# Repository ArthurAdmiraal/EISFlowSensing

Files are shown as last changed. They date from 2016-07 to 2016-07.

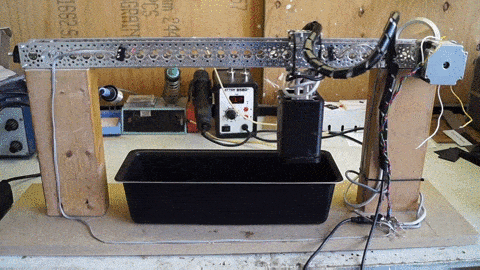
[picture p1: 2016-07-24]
Documentation/Render/CompleteSetup.gif

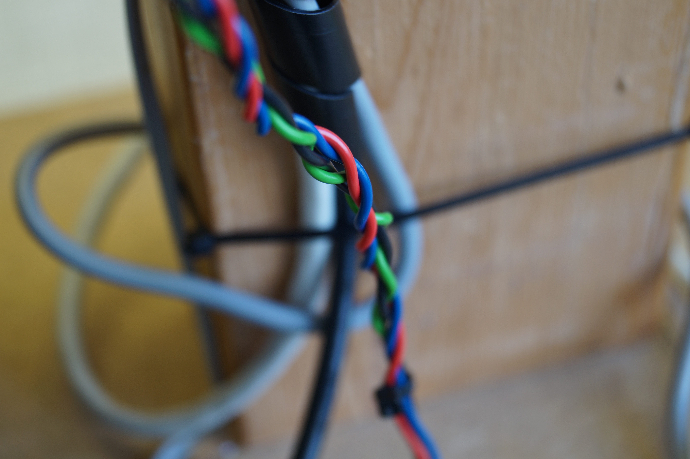
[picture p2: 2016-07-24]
Documentation/Render/StepperMotorWiring.jpg

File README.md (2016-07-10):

# Solid state flow sensing using Electrical Impedance Spectroscopy
This repository contains all files for the solid state flow sensing using EIS project, which is documented on hackaday.io, click [here](https://hackaday.io/project/12543-solid-state-flow-sensing-using-eis) to go there.

## License
You can use everything here under a[Creative Commons Attribution-ShareAlike 4.0 International](https://creativecommons.org/licenses/by-sa/4.0/) license.

## Repository structure
Inside the documentation folder, you'll find the source files for images used in the documentation of the project on hackaday.io, along with the rendered versions. The source images are either vector files, or images to large to be uploaded to hackaday.io. You can also find software examples for tutorials placed on hackaday.io there.

The design folder contains CAD files and CAM files needed for replicating the project. The electrical folder contains the KiCad projects for both the electrode and signal generator PCB, along with the gerbers to get them fabricated at [OSH Park](https://oshpark.com/). The mechanical folder contains some OpenScad files for 3D-printed parts, along with STLs for the files that take a long time to render.

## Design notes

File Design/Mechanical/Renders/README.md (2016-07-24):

#Renders
In this folder, you find all the stl files you need for 3D printing the RISA case. You could also download the OpenSCAD source file in the design folder if you want to edit the model or render our the files yourself, but since the rendering takes a long time (about half a hour for me) I have provided the rendered out files here too.

#The files
## Files to 3D-print
If you just want to build this project for yourself, you can simply download these files and hit print.

### RISA_Case_O_ring_USB_Space_top_fixed.stl
This is the top of the case, or the electrode holder part. The mesh was repaired from the source file using [Microsofts 3D printing cloud services](https://tools3d.azurewebsites.net/) to make it suitable for 3D printing.

### RISA_Case_O_ring_USB_Space_body.stl
This is the main body of the case. The mesh isn't watertight, as I wasn't able to repair it automatically. The slicer I use (Slic3r) didn't have any problems with it though.

## Additional files
###RISA_Case_O_ring_USB_Space_full.stl
This is the full case, in case you need it. It isn't really 3D-printable on entry-level 3D printers, but perhaps you want to do something fancier.

###RISA_Case_O_ring_USB_Space_top.stl
This is the top of the case, or the electrode holder part, as it rendered out of OpenSCAD. Unfortunately, the mesh isn't quite watertight, which can lead slicers to have problems with it. I have included it for completeness.

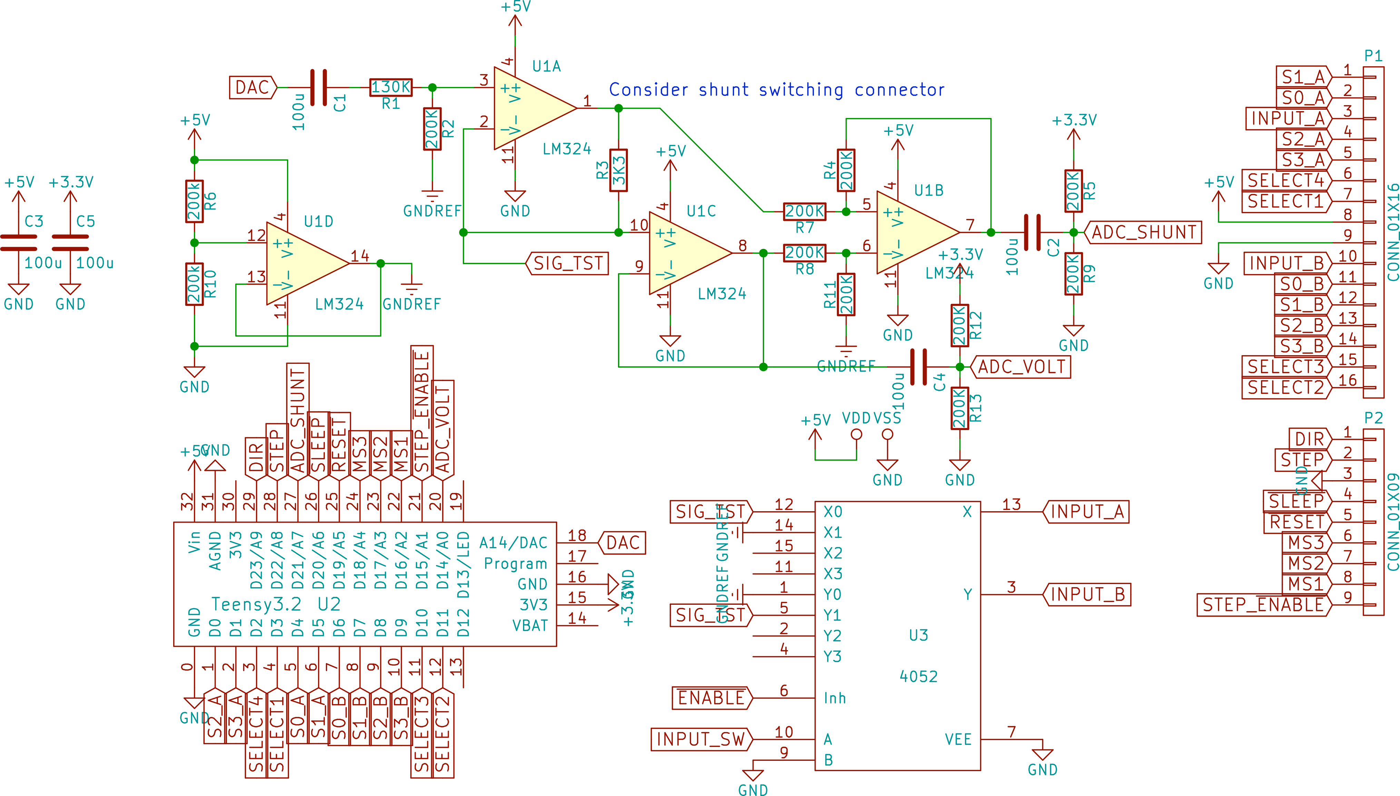
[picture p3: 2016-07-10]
Documentation/Render/SigGenSchematic.png

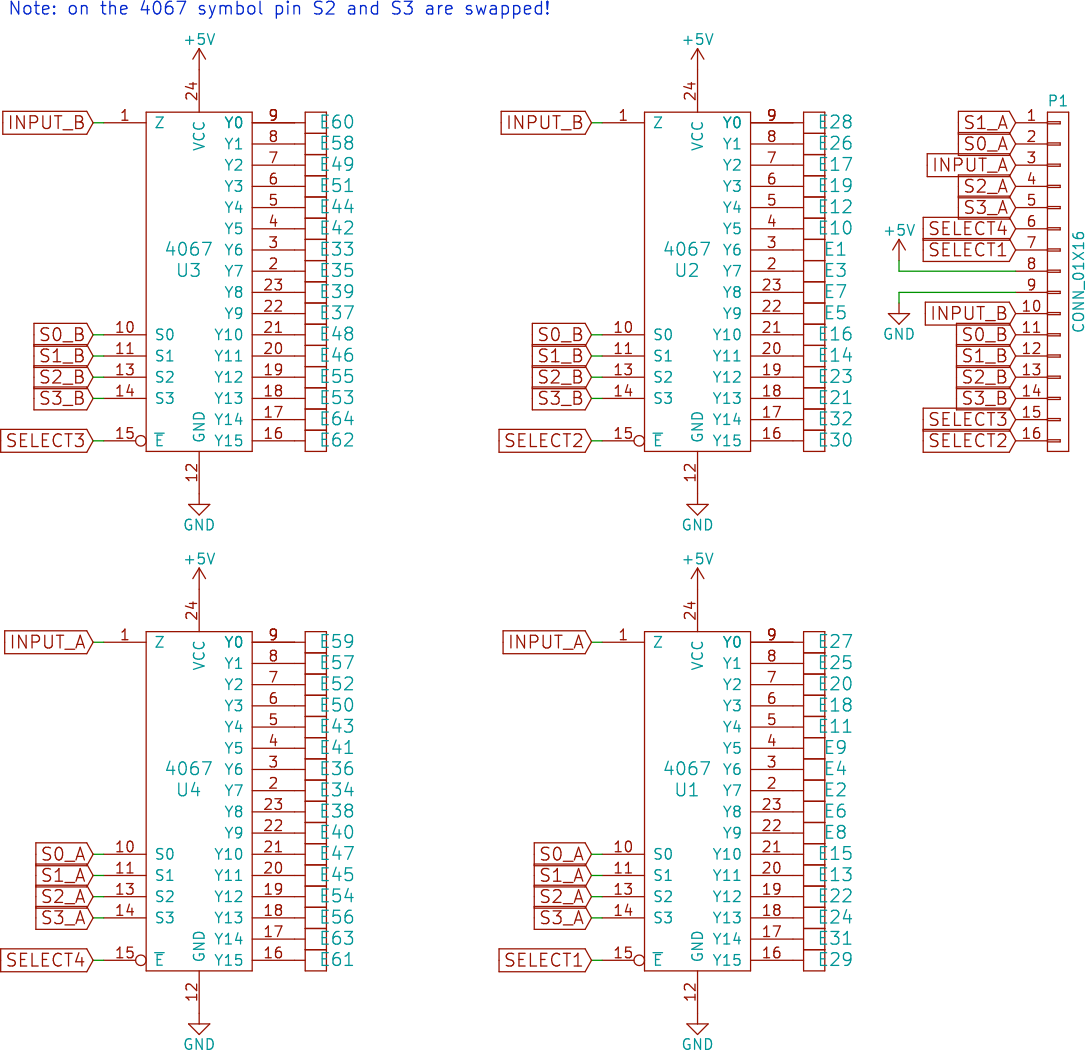
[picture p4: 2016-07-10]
Documentation/Render/ElectrodeSchematic.png

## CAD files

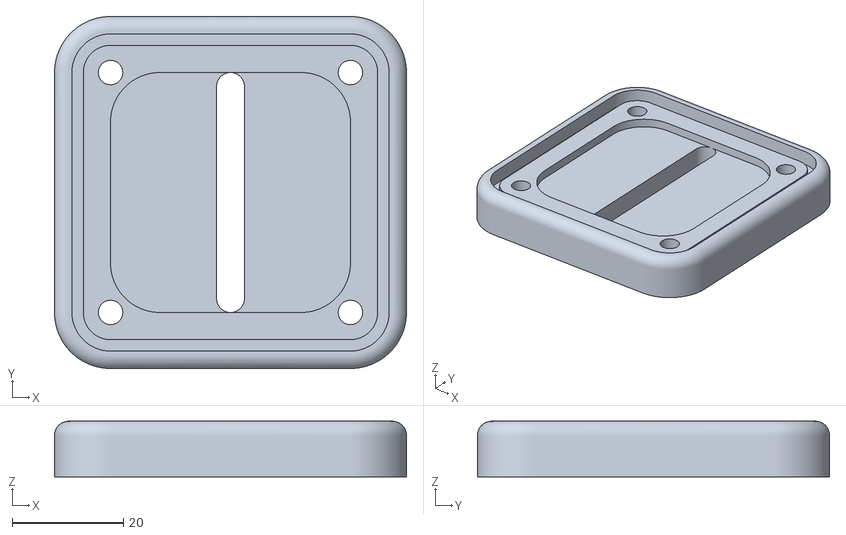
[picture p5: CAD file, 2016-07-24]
Design/Mechanical/Renders/RISA_Case_O_ring_USB_Space_top_fixed.stl
63.4 x 63.4 x 10.00

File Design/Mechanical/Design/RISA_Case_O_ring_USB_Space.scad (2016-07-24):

// quality settings
$fs = 0.05;
$fa = 2;

// CAM parameters
split = 10;

// parameters
margin          = 1.2;              // 1.2mm
topBevel        = 0.1*25.4;         // 0.1"
sideBevel       = 0.35*25.4+margin; // 0.35"
holeDist        = 0.85*25.4;        // 0.85"
height          = 100;              // 100mm
interconnect    = 12.8;             // 12.4mm, change this value
electrodeSize   = 2.2*25.4+margin;  // 2.2"
sigGenSize      = 2.0*25.4+margin*2;// 2.0"
pcbThickness    = 1.6;              // 1.6mm
holeSize        = 3.2 + margin;     // M3 clearance hole
componentSize   = 2.0;              // 2mm component clearance
componentRadius = 0.35*25.4;        // 0.35"
headerWidth     = 1.7*25.4;         // 1.7"
headerHeight    = 0.15*25.4+margin; // 0.15"
hubSize         = 1.061*25.4;       // 1.061"
hubOffset       = 0.22*25.4;        // 0.22"
hubHole         = 1.85+margin/2;    // #6-32 clearance radius, 1.85mm
hubWidth        = 2.05*25.4+margin; // 2.05"
hubHeight       = 1.25*25.4;        // 1.25"
hubRadius       = 0.75*25.4;        // 0.75"
angle           = 45;               // 45 degrees

extension      =  7+2*margin;
extensionBegin = 9;
extensionAngle = 45; // there is probably an error in calculations involving this angle, so best keep it on this
angleMargin    = 0.001;

extensionOffset = 2*sideBevel*(1-cos(extensionAngle));
slopedExtension = (extension - extensionOffset)/cos(extensionAngle);
extensionHeight = 2*sideBevel*sin(extensionAngle) + sin(extensionAngle)*slopedExtension;

// helper modules
// basic shapes
module torus(rminor, rmajor) {
    rotate_extrude() {
        translate([rmajor,0,0])
            circle(r=rminor);
    }
}

// building the object
// change intersection to difference for the bottom part
intersection() { difference() {
translate([0,0,-topBevel]) union() {
////////////////////////////////////////////////////////////
// top /////////////////////////////////////////////////////
////////////////////////////////////////////////////////////
union() {
// top corner bevels
for(o=[[1,1,0],[1,-1,0],[-1,1,0],[-1,-1,0]]) {
    translate(holeDist*o) {
        torus(topBevel, sideBevel-topBevel);
        cylinder(r=sideBevel-topBevel, h=2*topBevel, center=true);
    }
}

// top side bevels
for(o=[[1,0,0],[-1,0,0],[0,1,0],[0,-1,0]]) {
    translate((holeDist+sideBevel-topBevel)*o)
    rotate(90*o)
    cylinder(r=topBevel, h=2*holeDist, center=true);
}

// top filler
cube(2*[holeDist+sideBevel-topBevel,holeDist,topBevel], center=true);
cube(2*[holeDist,holeDist+sideBevel-topBevel,topBevel], center=true);
}

////////////////////////////////////////////////////////////
// main body ///////////////////////////////////////////////
////////////////////////////////////////////////////////////
// more comment comming for this part
translate([0,0,topBevel-height]) rotate([0,180,0]) union() {
// side bevels
translate([0,0,topBevel-height]) {
    for(o=[[1,-1,0],[-1,-1,0]]) {
        translate(holeDist*o)
        cylinder(r=sideBevel, h=height-topBevel);
    }
    
    for(o=[[1,1,0],[-1,1,0]]) {
        translate(holeDist*o)
        union() {
            cylinder(r=sideBevel, h=extensionBegin+angleMargin);
            
            translate([0,sideBevel,extensionBegin]) difference() {
                rotate([0,90,0])
                torus(sideBevel, sideBevel+angleMargin);
                translate([-sideBevel*1.05, 0, -sideBevel*2.1])
                cube([sideBevel*2.1, sideBevel*2.1, sideBevel*4.2]);
                translate([-sideBevel*1.05,-sideBevel*2.1,-sideBevel*2.1])
                cube([sideBevel*2.1, sideBevel*4.2, sideBevel*2.1]);
                translate([-sideBevel*1.05,0,0])
                rotate([extensionAngle-angleMargin,0,0])
                cube([sideBevel*2.1, sideBevel*2.1, sideBevel*2.1]);
            }
            
          translate([0,-sideBevel+extension,extensionBegin+extensionHeight]) {
                rotate([180,0,0]) difference(){
                rotate([0,90,0])
                torus(sideBevel, sideBevel+angleMargin);
                translate([-sideBevel*1.05, 0, -sideBevel*2.1])
                cube([sideBevel*2.1, sideBevel*2.1, sideBevel*4.2]);
                translate([-sideBevel*1.05,-sideBevel*2.1,-sideBevel*2.1])
                cube([sideBevel*2.1, sideBevel*4.2, sideBevel*2.1]);
                translate([-sideBevel*1.05,0,0])
                rotate([extensionAngle-angleMargin,0,0])
                cube([sideBevel*2.1, sideBevel*2.1, sideBevel*2.1]);
                }
            }
            translate([0,extension,extensionBegin+extensionHeight])
            cylinder(r=sideBevel, h=height-topBevel-extensionBegin-extensionHeight);
            
            translate([0,sideBevel,extensionBegin])
            rotate([-extensionAngle,0,0]) union() {
                translate([0,-sideBevel,0])
                cylinder(r=sideBevel, h=slopedExtension+angleMargin);
                translate([-sideBevel,-2*sideBevel,0])
                cube([2*sideBevel,sideBevel,slopedExtension+angleMargin]);
            }
        }
    }
}

translate([0,holeDist+extension-sideBevel,-height+topBevel+extensionBegin+extensionHeight])
rotate([0,90,0]) {
cylinder(r=sideBevel, h=2*(holeDist+sideBevel), center=true);
cylinder(r=2*sideBevel, h=2*(holeDist), center=true);
}

translate([-holeDist-sideBevel,holeDist+sideBevel,topBevel+extensionBegin-height]) {
    rotate([90-extensionAngle,0,0])
    translate([sideBevel,0,0])
    cube([2*holeDist, slopedExtension, sideBevel]);
difference() {
    translate([0,-sideBevel,0])
    cube([2*(holeDist+sideBevel),sideBevel,sideBevel]);
    translate([-0.05*(holeDist+sideBevel),0,0]) {
    rotate([0,90,0]) cylinder(r=sideBevel, h=2.1*(holeDist+sideBevel));
    rotate([extensionAngle,0,0])
    cube([2.1*(holeDist+sideBevel),2*sideBevel,2*sideBevel]);
    }
}
}

translate([0,0.5*extension,-0.5*(height-topBevel-extensionBegin-extensionHeight)]) {
cube([2*(holeDist+sideBevel),2*holeDist+extension,height-topBevel-extensionBegin-extensionHeight],center=true);
cube([2*holeDist,2*(holeDist+sideBevel)+extension,height-topBevel-extensionBegin-extensionHeight],center=true);
}

// main filler
translate(0.5*[0,0,topBevel-height]) {
cube([2*(holeDist+sideBevel),2*holeDist,height-topBevel],center=true);
cube([2*holeDist,2*(holeDist+sideBevel),height-topBevel],center=true);
}
}
}
////////////////////////////////////////////////////////////
// cutouts /////////////////////////////////////////////////
////////////////////////////////////////////////////////////
// main cutout
translate([0,0,-height-1]) {
    for(o=[[1,1,0],[-1,1,0],[1,-1,0],[-1,-1,0]]) {
        translate(holeDist*o)
        cylinder(r=0.5*sigGenSize-holeDist, h=height-pcbThickness-interconnect+1);
    }
    
    translate(0.5*[0,0,height-pcbThickness-interconnect+1]) {
        cube([sigGenSize,2*holeDist,height-pcbThickness-interconnect+1], center=true);
        cube([2*holeDist,sigGenSize,height-pcbThickness-interconnect+1], center=true);
    }
}

// USB cable cutout
translate([0,extension,-extensionBegin-height-1]) {
    for(o=[[1,1,0],[-1,1,0]]) {
        translate(holeDist*o)
        cylinder(r=0.5*sigGenSize-holeDist, h=height-pcbThickness-interconnect+1);
    }
    
    translate(0.5*[0,0,height-pcbThickness-interconnect+1]) {
        cube([sigGenSize,2*holeDist,height-pcbThickness-interconnect+1], center=true);
        cube([2*holeDist,sigGenSize,height-pcbThickness-interconnect+1], center=true);
    }
}

// electrode cutout
translate([0,0,-pcbThickness]) {
    for(o=[[1,1,0],[-1,1,0],[1,-1,0],[-1,-1,0]]) {
        translate(holeDist*o)
        cylinder(r=0.5*electrodeSize-holeDist, h=pcbThickness+1);
    }
    
    translate(0.5*[0,0,pcbThickness+1]) {
        cube([electrodeSize,2*holeDist,pcbThickness+1], center=true);
        cube([2*holeDist,electrodeSize,pcbThickness+1], center=true);
    }
}

// screw hole cutout
translate([0,0,-height]) {
    for(o=[[1,1,0],[-1,1,0],[1,-1,0],[-1,-1,0]]) {
        translate(holeDist*o)
        cylinder(d=holeSize, h=height);
    }
}

// top component clearance cutout
translate(-[0,0,pcbThickness+componentSize]) {
    for(o=[[1,1,0],[-1,1,0],[1,-1,0],[-1,-1,0]]) {
        translate((holeDist-componentRadius)*o)
        cylinder(r=componentRadius, h=componentSize+1);
    }
    
    translate(0.5*[0,0,componentSize+1]) {
        cube([2*(holeDist-componentRadius),2*holeDist,componentSize+1], center=true);
        cube([2*holeDist,2*(holeDist-componentRadius),componentSize+1], center=true);
    }
}

oRingDia = 2.0; // 2mm
ch       = 0.9; // height in the gland
ca       = 0.85; // fill quotient
oRingH   = ch*oRingDia;
oRingB   = PI*oRingDia/(4*ch*ca);
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

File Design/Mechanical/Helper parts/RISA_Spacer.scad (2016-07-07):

PCB_Height = 2.0;
Spacer = 12.5;
Insert = 3;
Clip = 2;
Structure = 2;
Width = 25;

cube([Spacer+2*(PCB_Height+Clip), Width, Structure]);

for(o=[0, Clip+PCB_Height, PCB_Height+Spacer, Clip+2*PCB_Height+Spacer]) {
    translate([o,0,0]) cube([Clip, Width, Structure+Insert]);
}

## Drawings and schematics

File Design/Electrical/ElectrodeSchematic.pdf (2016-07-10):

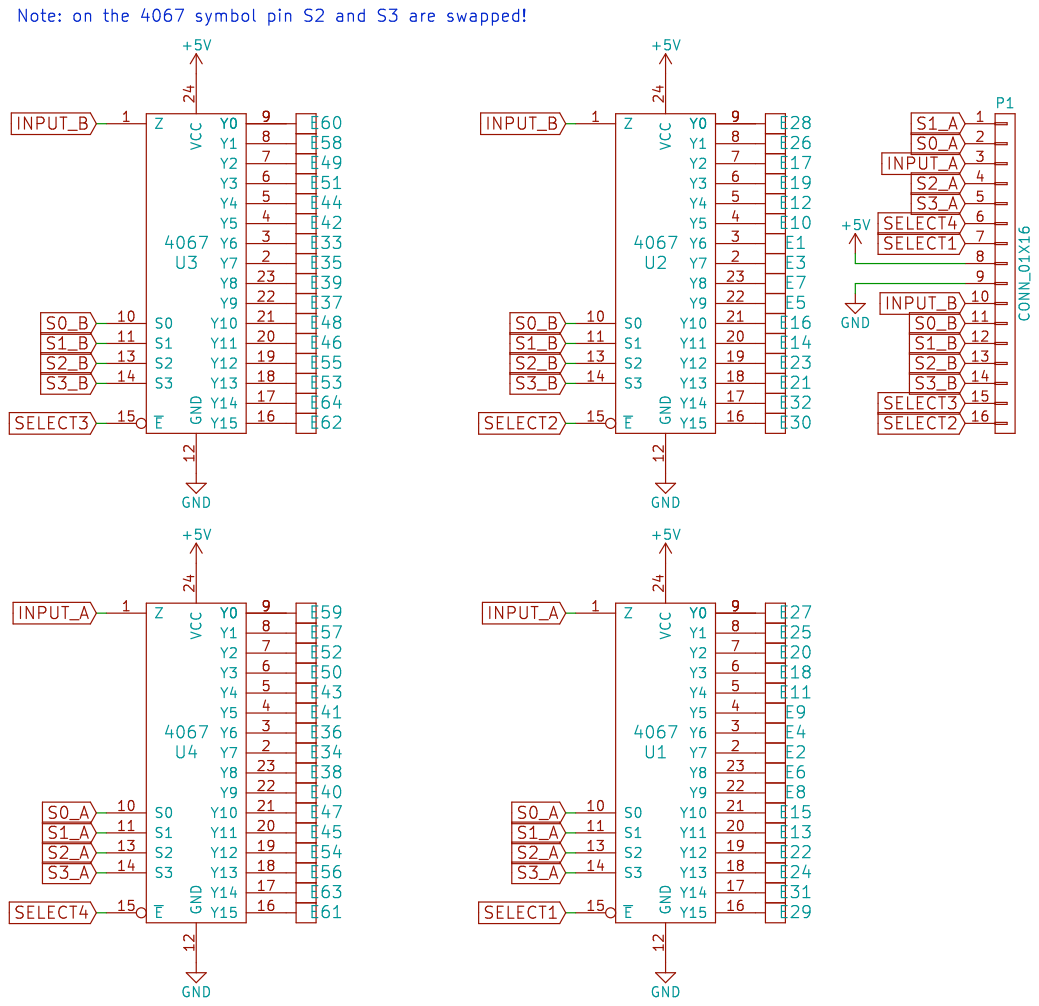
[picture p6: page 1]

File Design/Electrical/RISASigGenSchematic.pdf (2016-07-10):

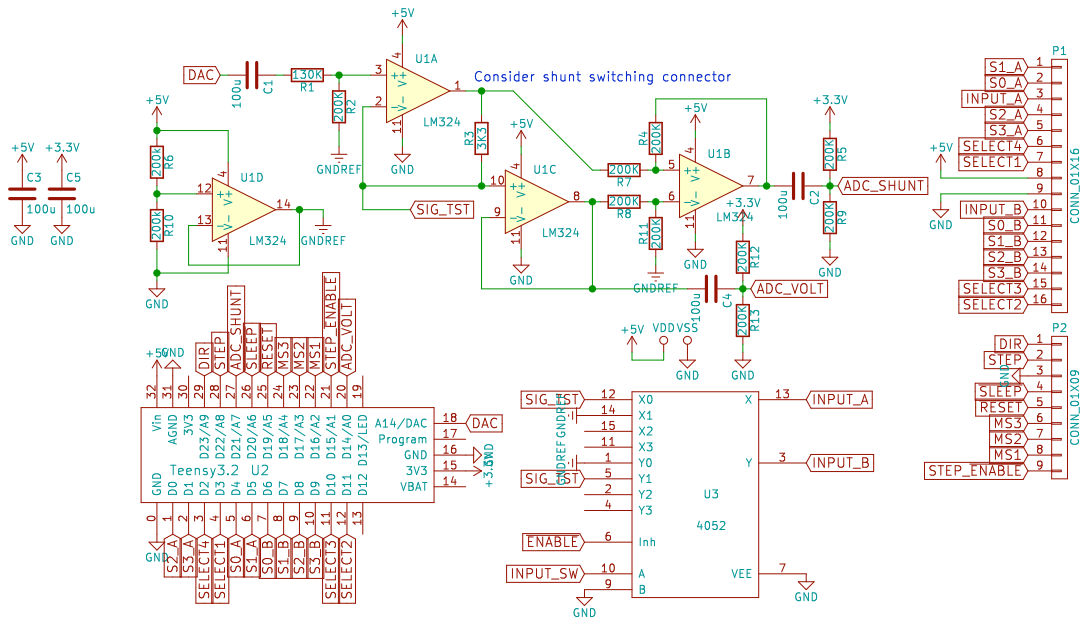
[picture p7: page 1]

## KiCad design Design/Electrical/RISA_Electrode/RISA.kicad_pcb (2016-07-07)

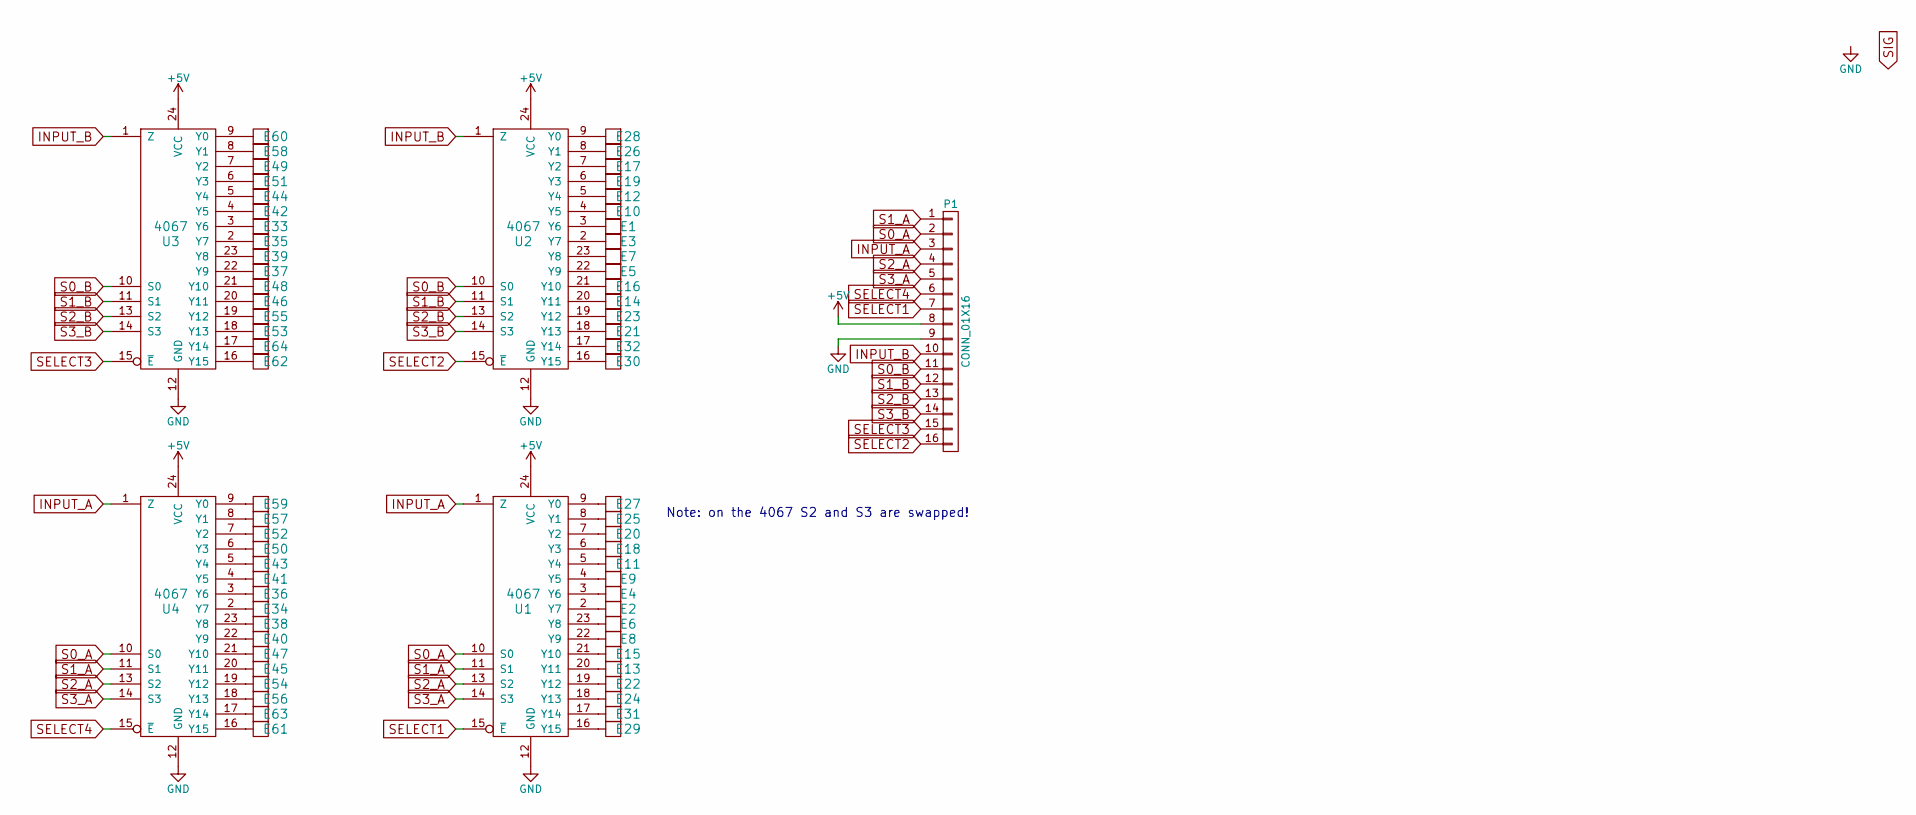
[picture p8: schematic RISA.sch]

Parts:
E1, E2, E3, E4, E5, E6, E7, E8, E9, E10, E11, E12, E13, E14, E15, E16, E17, E18, E19, E20, E21, E22, E23, E24, E25, E26, E27, E28, E29, E30, E31, E32, E33, E34, E35, E36, E37, E38, E39, E40, E41, E42, E43, E44, E45, E46, E47, E48, E49, E50, E51, E52, E53, E54, E55, E56, E57, E58, E59, E60, E61, E62, E63, E64: Electrode; ElectrodePad
P1: CONN_01X16; SMT_HEADER_1x16
U1, U2, U3, U4: 4067; SOIC-24_7.5x15.4mm_Pitch1.27mm

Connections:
+5V: P1.8, U1.24 (VCC), U2.24 (VCC), U3.24 (VCC), U4.24 (VCC)
GND: P1.9, U1.12 (GND), U2.12 (GND), U3.12 (GND), U4.12 (GND)
INPUT_A: P1.3, U1.1 (Z), U4.1 (Z)
INPUT_B: P1.10, U2.1 (Z), U3.1 (Z)
unnamed: E1.1, U2.3 (Y6)
unnamed: E2.1, U1.2 (Y7)
unnamed: E3.1, U2.2 (Y7)
unnamed: E4.1, U1.3 (Y6)
unnamed: E5.1, U2.22 (Y9)
unnamed: E6.1, U1.23 (Y8)
unnamed: E7.1, U2.23 (Y8)
unnamed: E8.1, U1.22 (Y9)
unnamed: E9.1, U1.4 (Y5)
unnamed: E10.1, U2.4 (Y5)
unnamed: E11.1, U1.5 (Y4)
unnamed: E12.1, U2.5 (Y4)
unnamed: E13.1, U1.20 (Y11)
unnamed: E14.1, U2.20 (Y11)
unnamed: E15.1, U1.21 (Y10)
unnamed: E16.1, U2.21 (Y10)
unnamed: E17.1, U2.7 (Y2)
unnamed: E18.1, U1.6 (Y3)
unnamed: E19.1, U2.6 (Y3)
unnamed: E20.1, U1.7 (Y2)
unnamed: E21.1, U2.18 (Y13)
unnamed: E22.1, U1.19 (Y12)
unnamed: E23.1, U2.19 (Y12)
unnamed: E24.1, U1.18 (Y13)
unnamed: E25.1, U1.8 (Y1)
unnamed: E26.1, U2.8 (Y1)
unnamed: E27.1, U1.9 (Y0)
unnamed: E28.1, U2.9 (Y0)
unnamed: E29.1, U1.16 (Y15)
unnamed: E30.1, U2.16 (Y15)
unnamed: E31.1, U1.17 (Y14)
unnamed: E32.1, U2.17 (Y14)
unnamed: E33.1, U3.3 (Y6)
unnamed: E34.1, U4.2 (Y7)
unnamed: E35.1, U3.2 (Y7)
unnamed: E36.1, U4.3 (Y6)
unnamed: E37.1, U3.22 (Y9)
unnamed: E38.1, U4.23 (Y8)
unnamed: E39.1, U3.23 (Y8)
unnamed: E40.1, U4.22 (Y9)
unnamed: E41.1, U4.4 (Y5)
unnamed: E42.1, U3.4 (Y5)
unnamed: E43.1, U4.5 (Y4)
unnamed: E44.1, U3.5 (Y4)
unnamed: E45.1, U4.20 (Y11)
unnamed: E46.1, U3.20 (Y11)
unnamed: E47.1, U4.21 (Y10)
unnamed: E48.1, U3.21 (Y10)
unnamed: E49.1, U3.7 (Y2)
unnamed: E50.1, U4.6 (Y3)
unnamed: E51.1, U3.6 (Y3)
unnamed: E52.1, U4.7 (Y2)
unnamed: E53.1, U3.18 (Y13)
unnamed: E54.1, U4.19 (Y12)
unnamed: E55.1, U3.19 (Y12)
unnamed: E56.1, U4.18 (Y13)
unnamed: E57.1, U4.8 (Y1)
unnamed: E58.1, U3.8 (Y1)
unnamed: E59.1, U4.9 (Y0)
unnamed: E60.1, U3.9 (Y0)
unnamed: E61.1, U4.16 (Y15)
unnamed: E62.1, U3.16 (Y15)
unnamed: E63.1, U4.17 (Y14)
unnamed: E64.1, U3.17 (Y14)
S0_A: P1.2, U1.10 (S0), U4.10 (S0)
S0_B: P1.11, U2.10 (S0), U3.10 (S0)
S1_A: P1.1, U1.11 (S1), U4.11 (S1)
S1_B: P1.12, U2.11 (S1), U3.11 (S1)
S2_A: P1.4, U1.13 (S2), U4.13 (S2)
S2_B: P1.13, U2.13 (S2), U3.13 (S2)
S3_A: P1.5, U1.14 (S3), U4.14 (S3)
S3_B: P1.14, U2.14 (S3), U3.14 (S3)
SELECT1: P1.7, U1.15 (~E)
SELECT2: P1.16, U2.15 (~E)
SELECT3: P1.15, U3.15 (~E)
SELECT4: P1.6, U4.15 (~E)

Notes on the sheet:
Note: on the 4067 S2 and S3 are swapped!

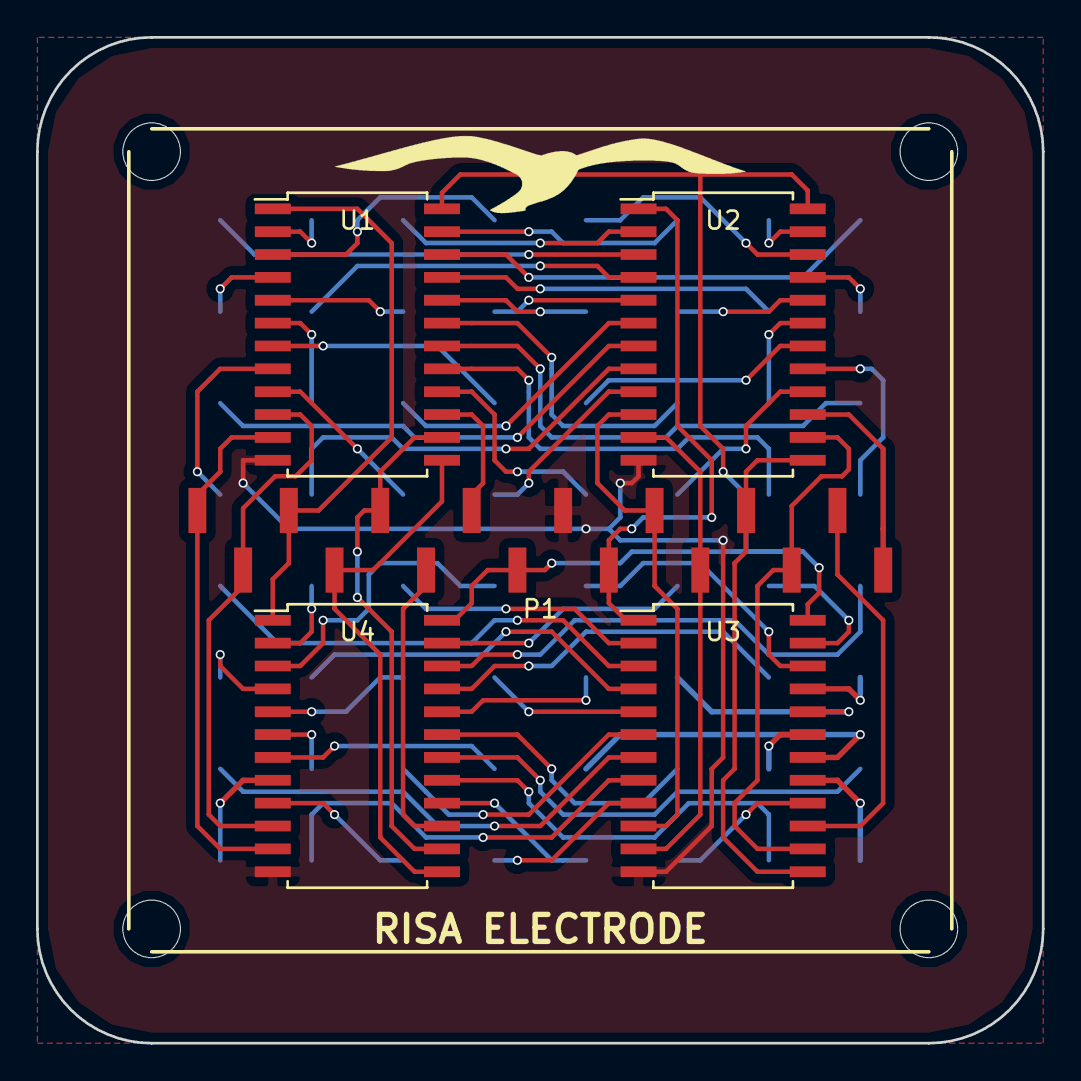
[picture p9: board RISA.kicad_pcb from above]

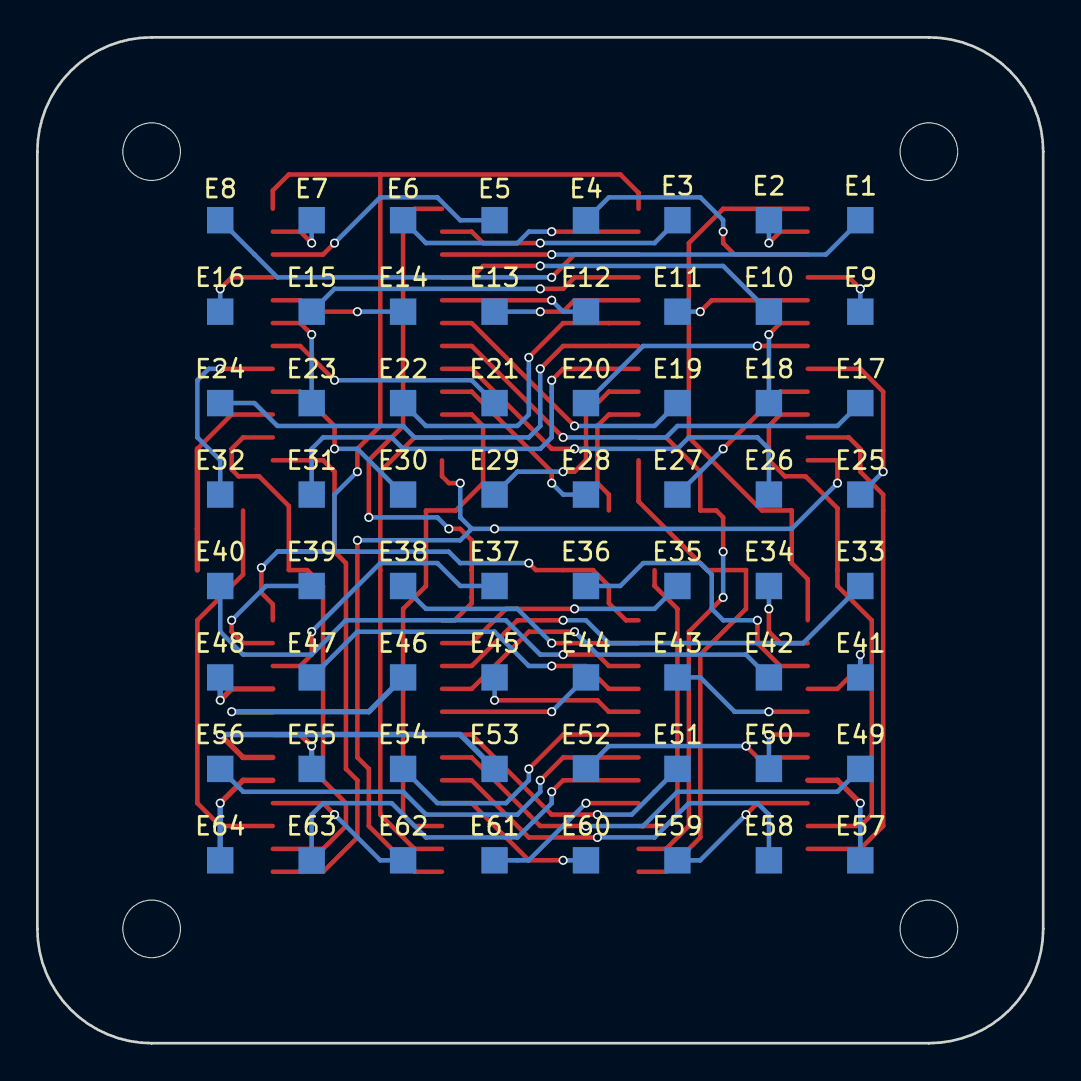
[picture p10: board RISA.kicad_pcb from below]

Board: 2 copper layers, 55.9 x 55.9 mm, 69 parts (64 on the bottom side), 80 nets.

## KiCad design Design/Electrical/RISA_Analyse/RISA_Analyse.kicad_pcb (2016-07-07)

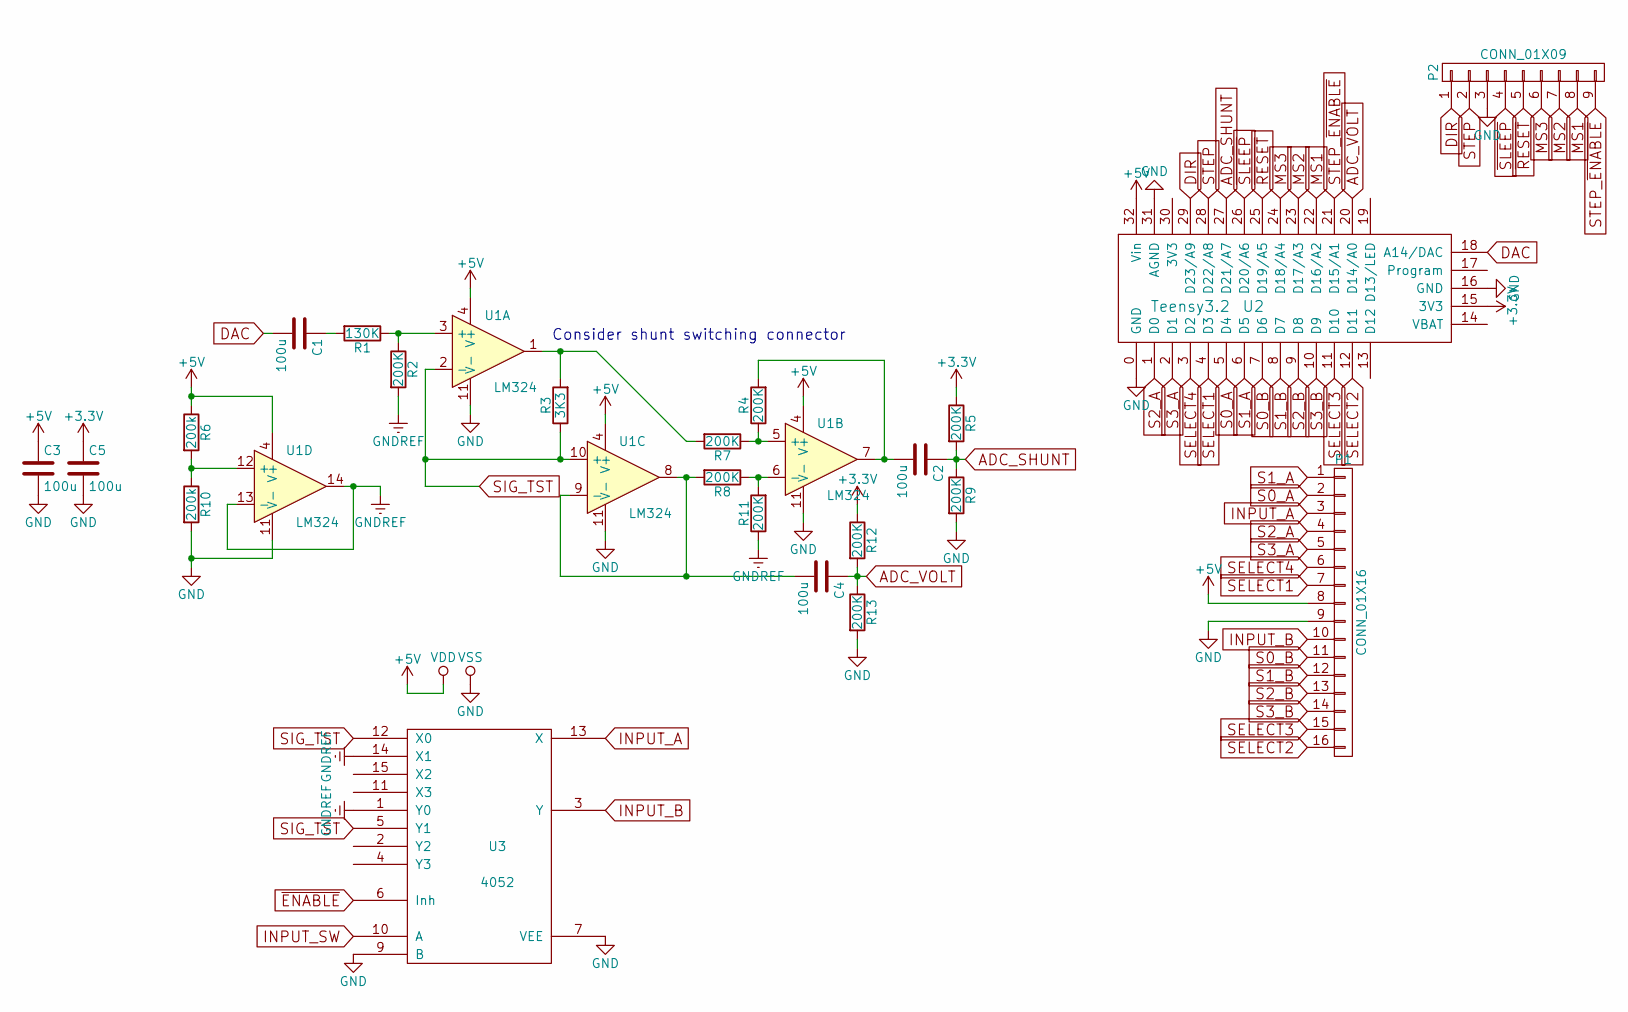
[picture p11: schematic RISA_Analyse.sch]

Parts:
C1, C2, C3, C4, C5: 100u; C_Rect_L7_W4.5_P5
P1: CONN_01X16; Pin_Header_Straight_1x16
P2: CONN_01X09; Pin_Header_Straight_1x09
R1: 130K; Resistor_Horizontal_RM7mm
R2, R4, R5, R7, R8, R9, R11, R12, R13: 200K; Resistor_Horizontal_RM7mm
R3: 3K3; Resistor_Horizontal_RM7mm
R6, R10: 200k; Resistor_Horizontal_RM7mm
U1: LM324; DIP-14_W7.62mm
U2: Teensy3.2
U3: 4052; DIP-16_W7.62mm

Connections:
+3V3: C5.1, R5.1, R12.1, U2.15 (3V3)
+5V: C3.1, P1.8, R6.1, U1.4 (V+), U2.32 (Vin), U3.16 (VDD)
ADC_SHUNT: C2.1, R5.2, R9.1, U2.27 (D21/A7)
ADC_VOLT: C4.1, R12.2, R13.1, U2.20 (D14/A0)
DAC: C1.2, U2.18 (A14/DAC)
DIR: P2.1, U2.29 (D23/A9)
GND: C3.2, C5.2, P1.9, P2.3, R9.2, R10.2, R13.2, U1.11 (V-), U2.0 (GND), U2.16 (GND), U2.31 (AGND), U3.7 (VEE), U3.8 (VSS), U3.9 (B)
GNDREF: R2.2, R11.1, U1.13 (-), U1.14, U3.1 (Y0), U3.14 (X1)
INPUT_A: P1.3, U3.13 (X)
INPUT_B: P1.10, U3.3 (Y)
INPUT_SW: U3.10 (A)
MS1: P2.8, U2.22 (D16/A2)
MS2: P2.7, U2.23 (D17/A3)
MS3: P2.6, U2.24 (D18/A4)
unnamed: C1.1, R1.2
unnamed: C2.2, R4.2, U1.7
unnamed: C4.2, R8.2, U1.8, U1.9 (-)
unnamed: R1.1, R2.1, U1.3 (+)
unnamed: R3.2, R7.2, U1.1
unnamed: R4.1, R7.1, U1.5 (+)
unnamed: R6.2, R10.1, U1.12 (+)
unnamed: R8.1, R11.2, U1.6 (-)
S0_A: P1.2, U2.5 (D4)
S0_B: P1.11, U2.7 (D6)
S1_A: P1.1, U2.6 (D5)
S1_B: P1.12, U2.8 (D7)
S2_A: P1.4, U2.1 (D0)
S2_B: P1.13, U2.9 (D8)
S3_A: P1.5, U2.2 (D1)
S3_B: P1.14, U2.10 (D9)
SELECT1: P1.7, U2.4 (D3)
SELECT2: P1.16, U2.12 (D11)
SELECT3: P1.15, U2.11 (D10)
SELECT4: P1.6, U2.3 (D2)
SIG_TST: R3.1, U1.2 (-), U1.10 (+), U3.5 (Y1), U3.12 (X0)
STEP: P2.2, U2.28 (D22/A8)
STEP_~ENABLE: P2.9, U2.21 (D15/A1)
~ENABLE: U3.6 (Inh)
~RESET: P2.5, U2.25 (D19/A5)
~SLEEP: P2.4, U2.26 (D20/A6)

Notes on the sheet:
Consider shunt switching connector

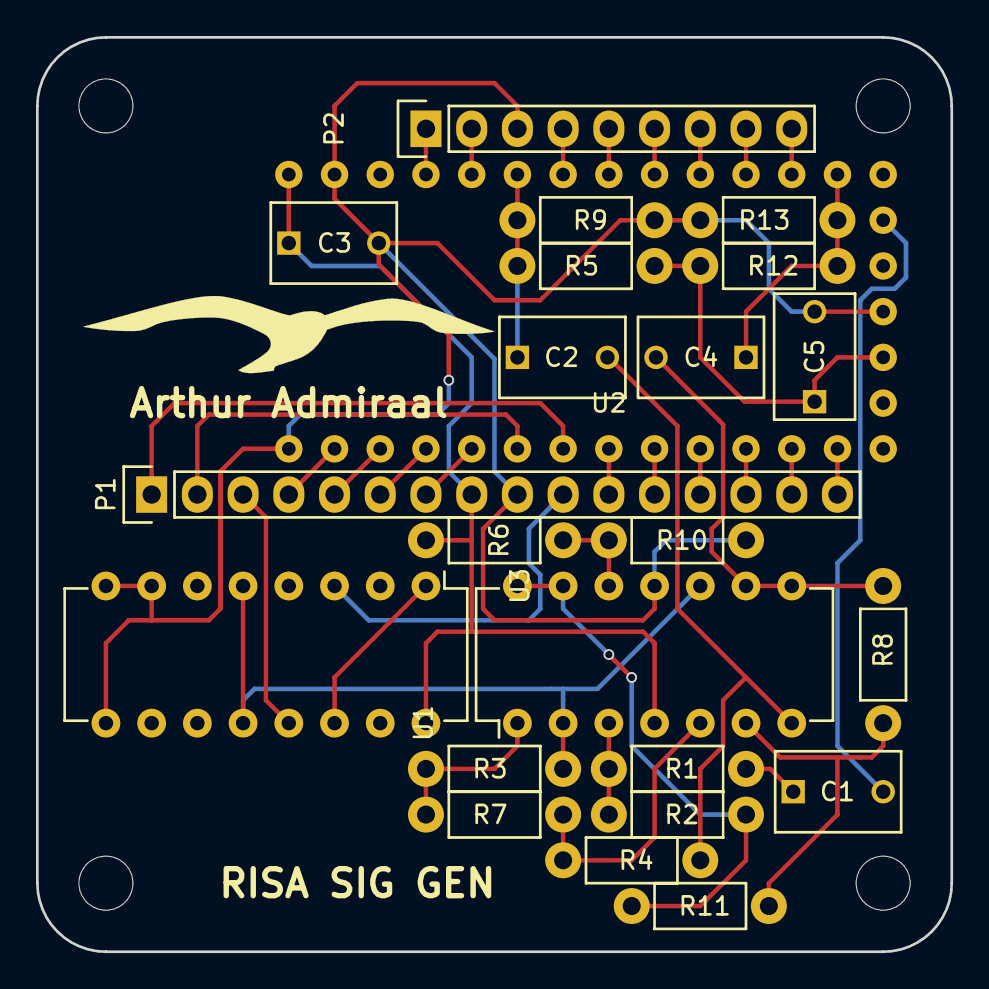
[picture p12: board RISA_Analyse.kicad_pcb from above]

Board: 2 copper layers, 50.8 x 50.8 mm, 23 parts (0 on the bottom side), 38 nets.

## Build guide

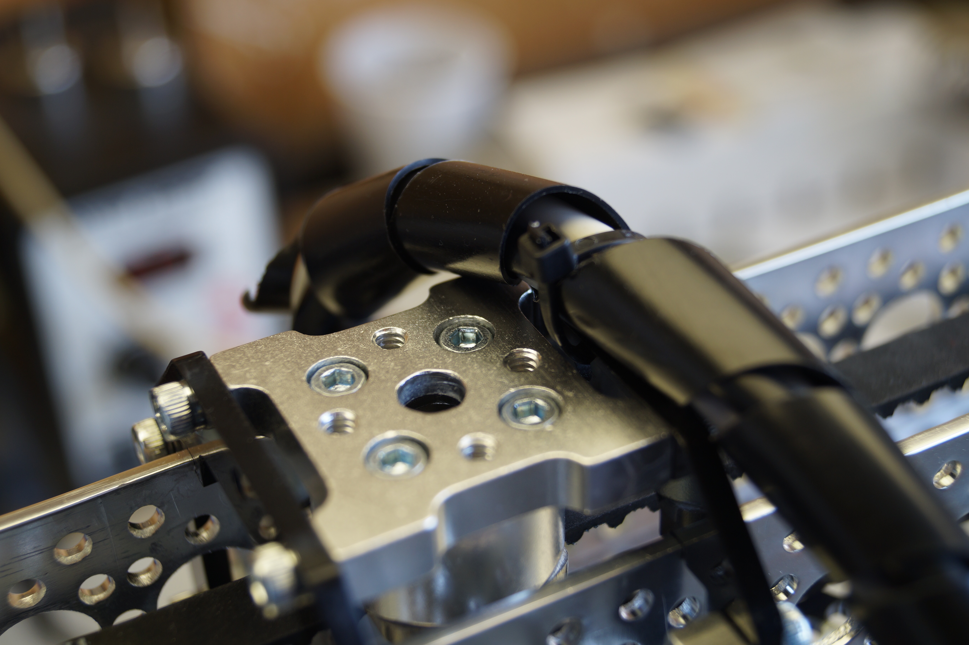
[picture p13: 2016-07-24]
Documentation/Render/CableGuideTie.jpg

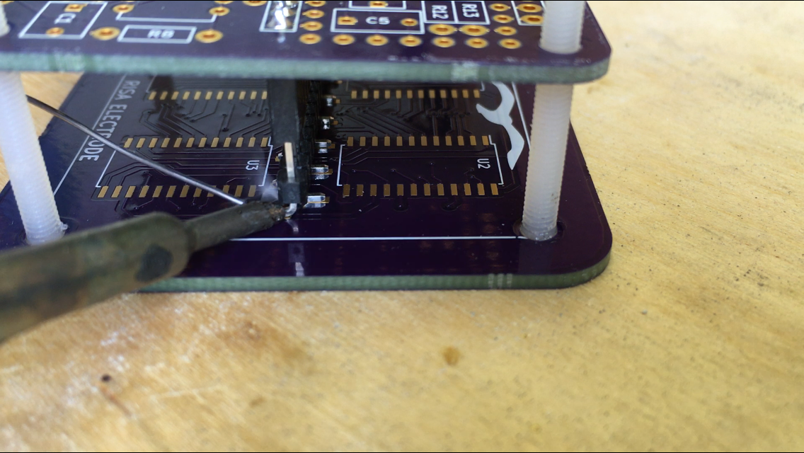
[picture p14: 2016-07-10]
Documentation/Render/BuildProcess.png

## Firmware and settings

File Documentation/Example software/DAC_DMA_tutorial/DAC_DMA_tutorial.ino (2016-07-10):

#define BUFFER_SIZE 480
static volatile uint16_t sinetable[BUFFER_SIZE];

void setup() {
  // fill up the sine table
  for(int i=0; i<BUFFER_SIZE; i++) {
    sinetable[i] = 2048+(int)(2048*sin(((float)i)*20.0*6.28318530717958647692/((float)BUFFER_SIZE)));
  }

  // initialise the DAC
  SIM_SCGC2 |= SIM_SCGC2_DAC0; // enable DAC clock
  DAC0_C0 = DAC_C0_DACEN | DAC_C0_DACRFS; // enable the DAC module, 3.3V reference

  // slowly ramp up to DC voltage
  for (int16_t i=0; i<2048; i+=1) {
    *(int16_t *)&(DAC0_DAT0L) = i;
    delayMicroseconds(125); // this function may be broken
  }

  // fill up the buffer with 2048
  for (int16_t i=0; i<16; i+=1) {
    *(int16_t *)(&DAC0_DAT0L + 2*i) = 2048;//256*(16-i) - 1;
  }

  // initialise the DMA
  // first, we need to init the dma and dma mux
  // to do this, we enable the clock to DMA and DMA MUX using the system timing registers
  SIM_SCGC6 |= SIM_SCGC6_DMAMUX; // enable DMA MUX clock
  SIM_SCGC7 |= SIM_SCGC7_DMA;    // enable DMA clock

  // next up, the channel in the DMA MUX needs to be configured
  DMAMUX0_CHCFG0 |= DMAMUX_SOURCE_DAC0; //Select DAC as request source
  DMAMUX0_CHCFG0 |= DMAMUX_ENABLE;      //Enable DMA channel 0

  // then, we enable requests on our channel
  DMA_ERQ = DMA_ERQ_ERQ0; // Enable requests on DMA channel 0

  // first, we need to init the dma and dma mux
  // to do this, we enable the clock to DMA and DMA MUX using the system timing registers
  SIM_SCGC6 |= SIM_SCGC6_DMAMUX; // enable DMA MUX clock
  SIM_SCGC7 |= SIM_SCGC7_DMA;    // enable DMA clock

  // next up, the channel in the DMA MUX needs to be configured
  DMAMUX0_CHCFG0 |= DMAMUX_SOURCE_DAC0; //Select DAC as request source
  DMAMUX0_CHCFG0 |= DMAMUX_ENABLE;      //Enable DMA channel 0

  // then, we enable requests on our channel
  DMA_ERQ = DMA_ERQ_ERQ0; // Enable requests on DMA channel 0

  // Here we choose where our data is coming from, and where it is going
  DMA_TCD0_SADDR = sinetable;   // set the address of the first byte in our LUT as the source address
  DMA_TCD0_DADDR = &DAC0_DAT0L; // set the first data register as the destination address

  // now we need to set the read and write offsets - kind of boring
  DMA_TCD0_SOFF = 4; // advance 32 bits, or 4 bytes per read
  DMA_TCD0_DOFF = 4; // advance 32 bits, or 4 bytes per write

  // this is the fun part! Now we get to set the data transfer size...
  DMA_TCD0_ATTR  = DMA_TCD_ATTR_SSIZE(DMA_TCD_ATTR_SIZE_32BIT);
  DMA_TCD0_ATTR |= DMA_TCD_ATTR_DSIZE(DMA_TCD_ATTR_SIZE_32BIT) | DMA_TCD_ATTR_DMOD(31 - __builtin_clz(32)); // set the data transfer size to 32 bit for both the source and the destination

  // ...and the number of bytes to be transferred per request (or 'minor loop')...
  DMA_TCD0_NBYTES_MLNO = 16; // we want to fill half of the DAC buffer, which is 16 words in total, so we need 8 words - or 16 bytes - per transfer

  // set the number of minor loops (requests) in a major loop
  // the circularity of the buffer is handled by the modulus functionality in the TCD attributes
  DMA_TCD0_CITER_ELINKNO = DMA_TCD_CITER_ELINKYES_CITER(BUFFER_SIZE*2/16);
  DMA_TCD0_BITER_ELINKNO = DMA_TCD_BITER_ELINKYES_BITER(BUFFER_SIZE*2/16);

  // the address is adjusted by these values when a major loop completes
  // we don't need this for the destination, because the circularity of the buffer is already handled
  DMA_TCD0_SLAST    = -BUFFER_SIZE*2;
  DMA_TCD0_DLASTSGA = 0;

  // do the final init of the channel
  DMA_TCD0_CSR = 0;

  // enable DAC DMA
  DAC0_C0 |= DAC_C0_DACBBIEN | DAC_C0_DACBWIEN; // enable read pointer bottom and waterwark interrupt
  DAC0_C1 |= DAC_C1_DMAEN | DAC_C1_DACBFEN | DAC_C1_DACBFWM(3); // enable dma and buffer
  DAC0_C2 |= DAC_C2_DACBFRP(0);

  // init the PDB for DAC interval generation
  SIM_SCGC6 |= SIM_SCGC6_PDB; // turn on the PDB clock  
  PDB0_SC |= PDB_SC_PDBEN; // enable the PDB  
  PDB0_SC |= PDB_SC_TRGSEL(15); // trigger the PDB on software start (SWTRIG)  
  PDB0_SC |= PDB_SC_CONT; // run in continuous mode  
  PDB0_MOD = 20-1; // modulus time for the PDB  
  PDB0_DACINT0 = (uint16_t)(20-1); // we won't subdivide the clock... 
  PDB0_DACINTC0 |= 0x01; // enable the DAC interval trigger  
  PDB0_SC |= PDB_SC_LDOK; // update pdb registers  

  PDB0_SC |= PDB_SC_SWTRIG; // ...and start the PDB
}

void loop() {
  // do nothing
}

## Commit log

2016-07-10 Adds electrical documentation and schematic pdfs
2016-07-10 Adds DAC buffered DMA example
2016-07-24 Updates mechanical design
    [RISA_Case_O_ring_USB_Space.scad]
2016-07-24 Adds mechanical renders
    [RISA_Case_O_ring_USB_Space_top_fixed.stl]
2016-07-24 Adds case documentation
